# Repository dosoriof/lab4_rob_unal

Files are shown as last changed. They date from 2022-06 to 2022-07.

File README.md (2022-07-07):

# Laboratorio 4 - Robótica Industrial IRB140 
- Rafael Ricardo Galindo
- Diego Fabian Osorio Fonseca
- Christian Cuestas

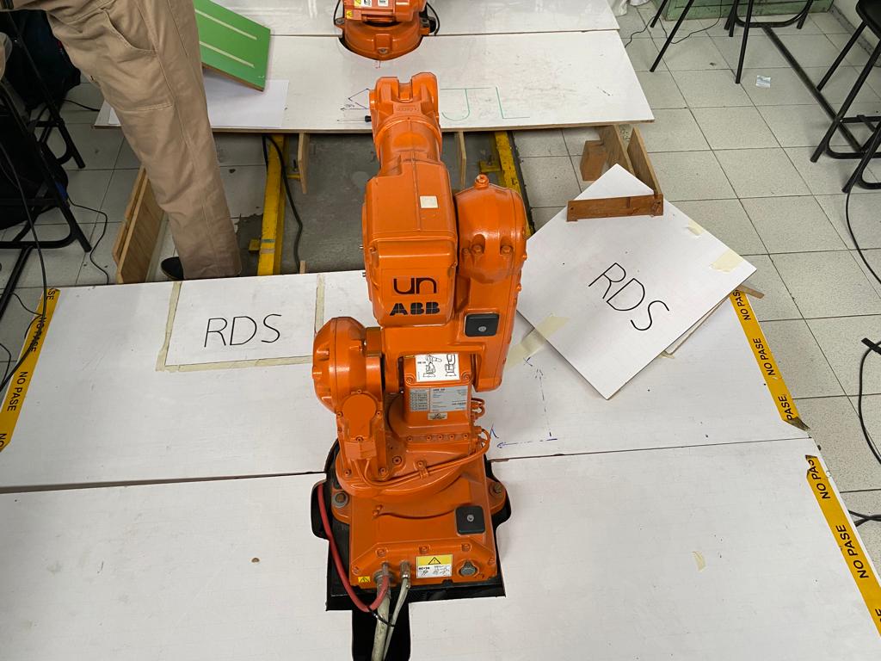
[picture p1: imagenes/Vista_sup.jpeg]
Vista superior


## Herramienta

### Diseño

Para el proceso de fabricación de la herramiento de planteó realizarlo en un modelo CAD y posteriormente realizar la respectiva impresión 3D. El modelo CAD se muestra a continuación:

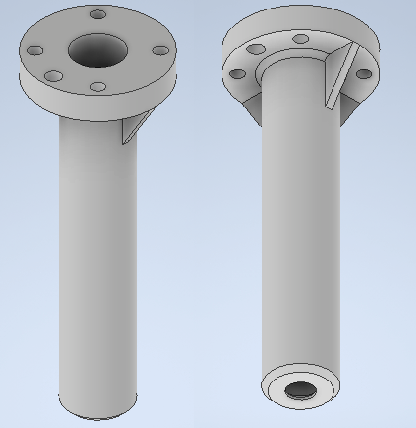
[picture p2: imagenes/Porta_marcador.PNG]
CAD herramienta


Se compone de una base con agujeros M6 (según el manual) para atornillarla a la superficie de anclaje del Robot y además un cilindro hueco para introducir el marcador, con unas cartelas para darle más soporte. El plano con los detalles de las medidas se presenta aquí, y el PDF está en la carpeta:

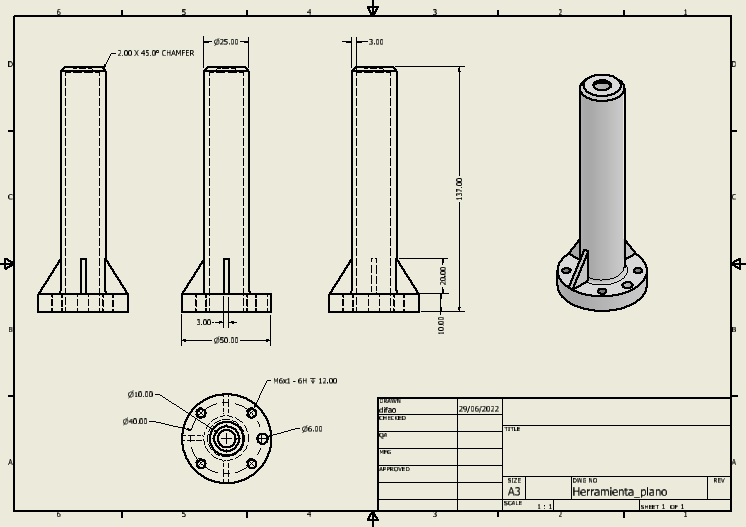
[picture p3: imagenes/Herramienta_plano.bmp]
plano herramienta


Para permitir un juego en el marcador que hace que exista menos resistencia en el momento de realizar los trazos, se dejo un espacio libre en el cilindro y allí se introdujo un resorte, que permite una retracción en el marcador cuando se realiza el contacto con la superficie:

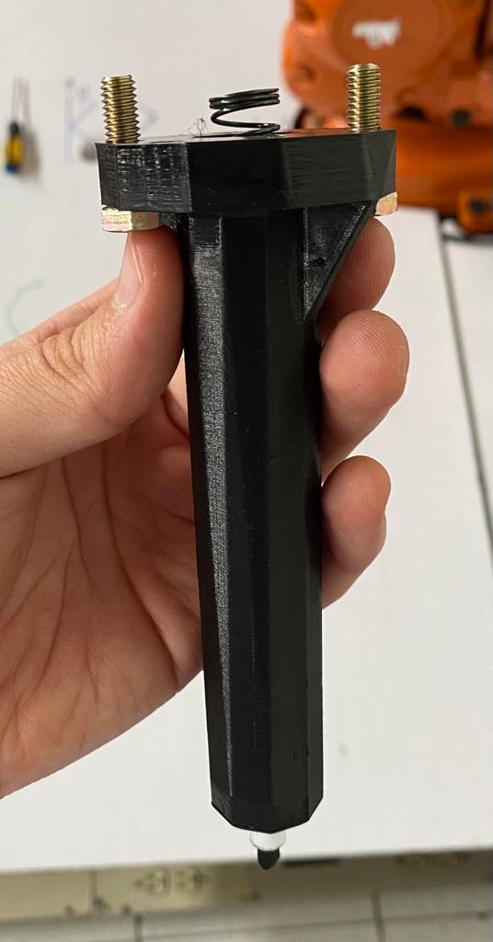
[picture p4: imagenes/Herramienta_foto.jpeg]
herramienta


### Calibración de herramienta en RobotStudio y en IRB140.  
#### Calibración de herramienta en RobotStudio.  
En el modelo de RobotStudio se realiza la importación de la geometría STL de la herramienta, como se muestra en la siguiente imagen:  

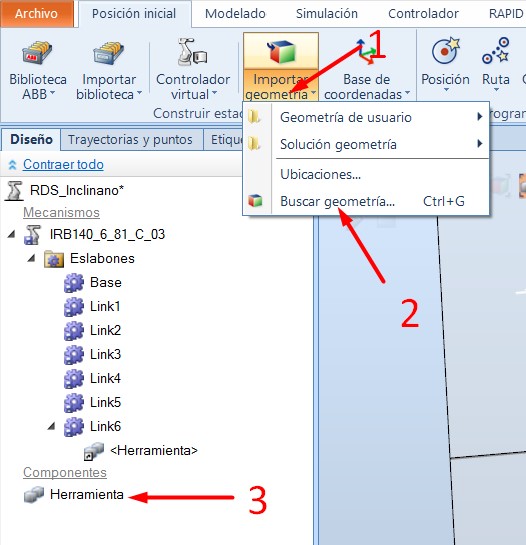
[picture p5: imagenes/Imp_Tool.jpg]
Importar herramienta RobotSutio
   

Teniendo importada la herramienta esta nos aparece posicionada en el origen de la base, en este caso se arrastra en la pestaña de diseño sobre el robot y de esta forma ella se vincula al sistema de coordenadas de la herramienta, sin embargo, la escala no es la correcta, para solucionarlo se siguen los siguientes pasos:

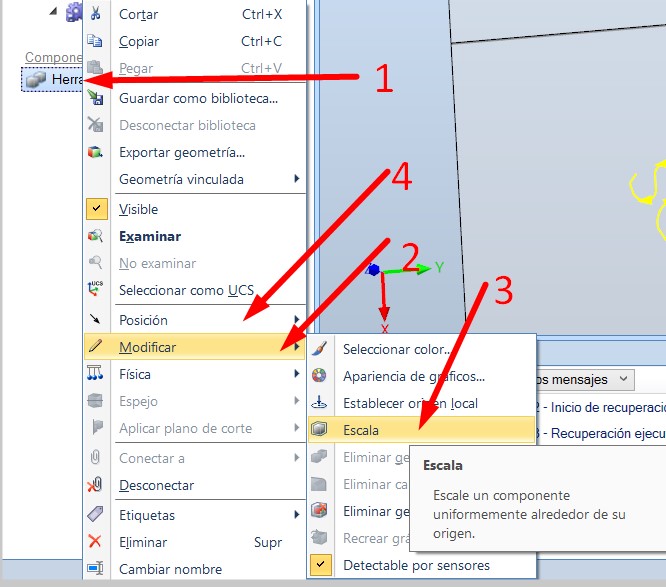
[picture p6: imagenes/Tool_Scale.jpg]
Escalar herramienta
    

Se realiza un proceso similar para ajustar la orientación de la herramienta de forma que quede posicionada correctamente.  
Luego de tener configurada la herramienta se procede a realizar la configuración del sistema de coordenadas de herramienta, para ello se realiza el siguiente proceso:  
Primero se debe crear el dato de la herramienta asi:  

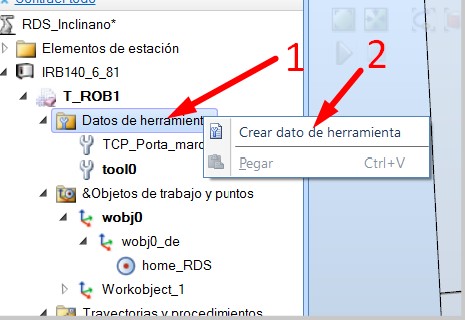
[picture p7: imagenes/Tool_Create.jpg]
Creación del Data Tool.
   

Luego se configura la posición y orientación del sistema de coordenadas de efector final, así:  
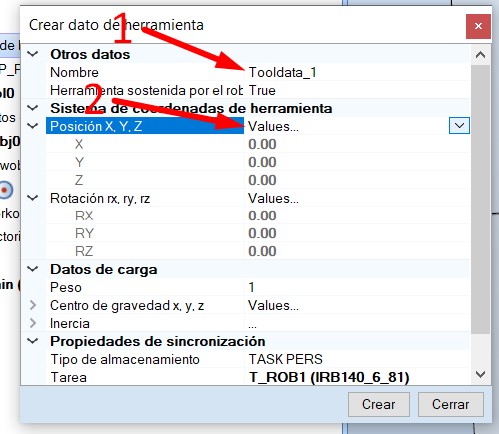
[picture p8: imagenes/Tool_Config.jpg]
Configuración TCP de la herramienta.
   
En este caso de acurdo a la geometría del portaherramientas y la longitud que sobresale del marcador desde la punta se sabe que la herramienta presenta un desfase de 150 mm desde la base de anclaje, se usa este valor para realizar la configuración y se verifica la posición de dicho TCP.  
#### Calibración de herramienta en IRB140 y IRC5.  
Inicialmente se entra a la ventana de Program Data, se selecciona en la pantalla principal tooldata, como se muestra a continuación:  
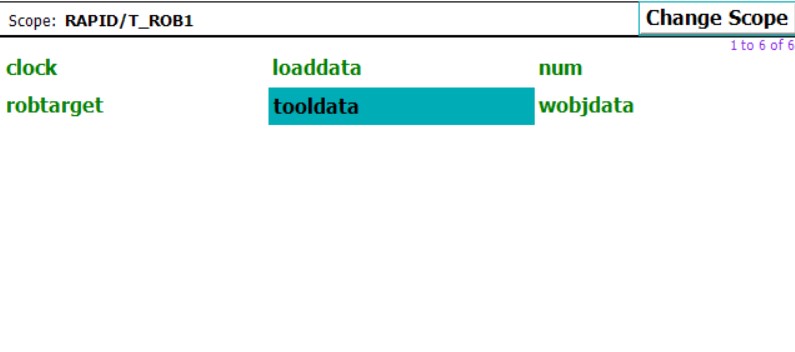
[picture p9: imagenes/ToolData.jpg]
Creación del Data Tool.
   
Luego se da en New, así:  
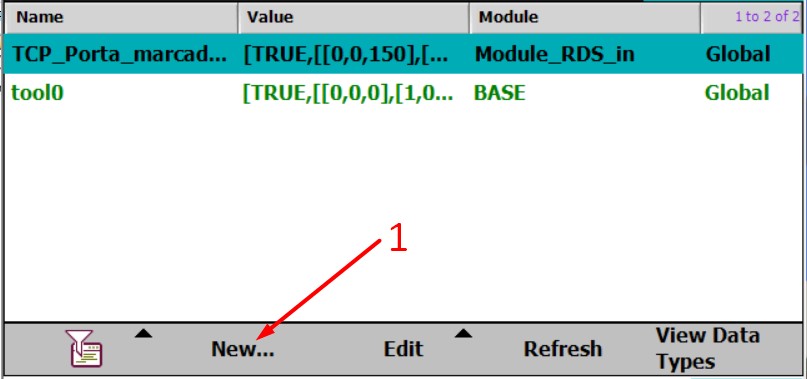
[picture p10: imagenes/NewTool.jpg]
Creación del Data Tool.
   
Luego se le asigna un nombre a la herramienta, y se crea, asi:   
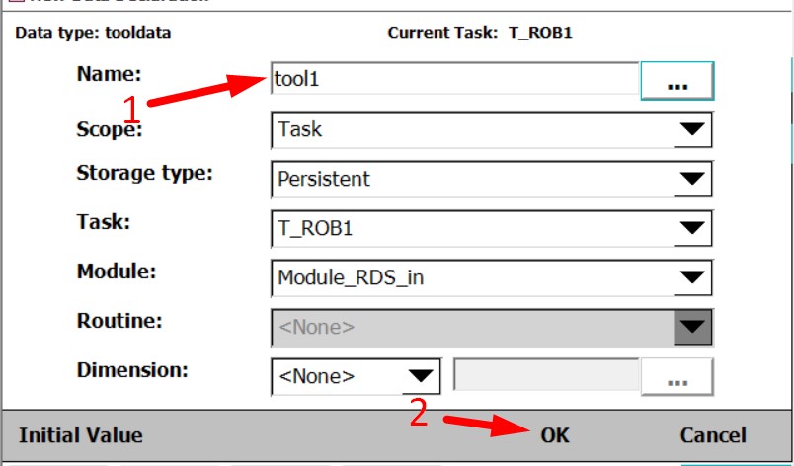
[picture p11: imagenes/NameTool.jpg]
Creación del Data Tool.
   
Luego se selecciona la herramienta recién creada y se inicia el proceso de definición de su configuración, así:  
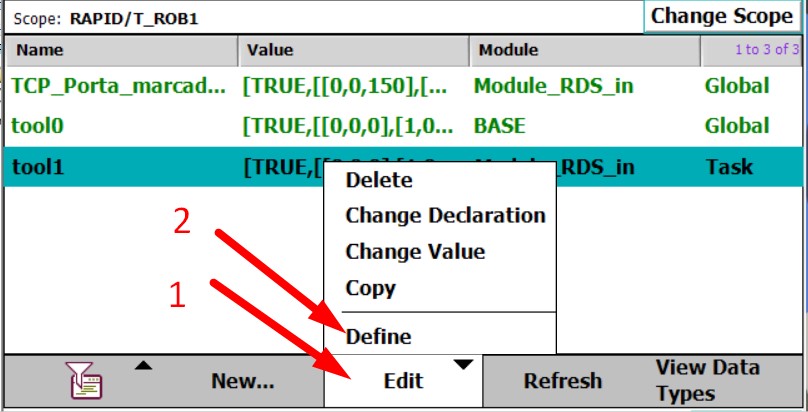
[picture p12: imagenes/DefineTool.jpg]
Creación del Data Tool.
   
En este caso se realiza la definición de la herramienta con 4 puntos en diferentes orientaciones y un punto vertical, para ello se selecciona TPC & Z, así:  
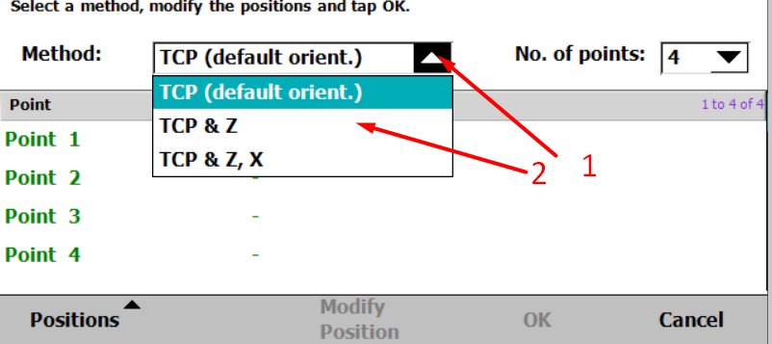
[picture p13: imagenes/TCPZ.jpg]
   
Luego se hace Jogging con el robot hasta las orientaciones y posiciones indicadas en las que la punta de la herramienta alcance la misma posición absoluta, de esta forma el programa puede calcular los desplazamientos relativos que tiene el TCP de la herramienta y adicionalmente calcula con que error esta dado ese punto, de acuerdo a la precisión obtenida en el posicionamiento del robot, esto se hace como se muestra a continuación:   
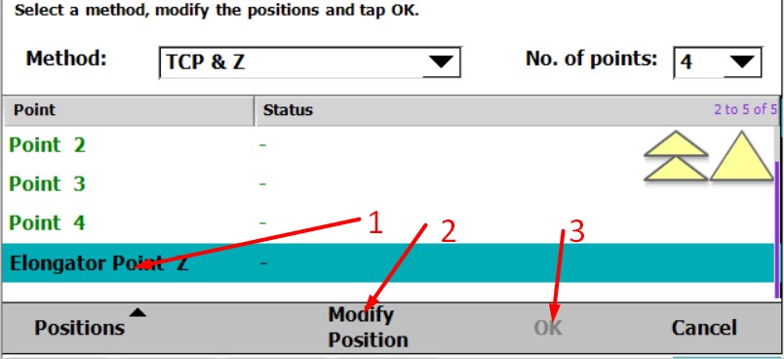
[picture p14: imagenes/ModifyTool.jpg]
Creación del Data Tool.
   

## Trayectorias
### Diseño Trayectoria. 
Para genera la trayectoria se realizó un dibujo en AutoCAD de forma que nos permitirá visualizar la trayectoria deseada y extraer los putos de los vértices y los centros de los arcos, como se muestra a continuación:
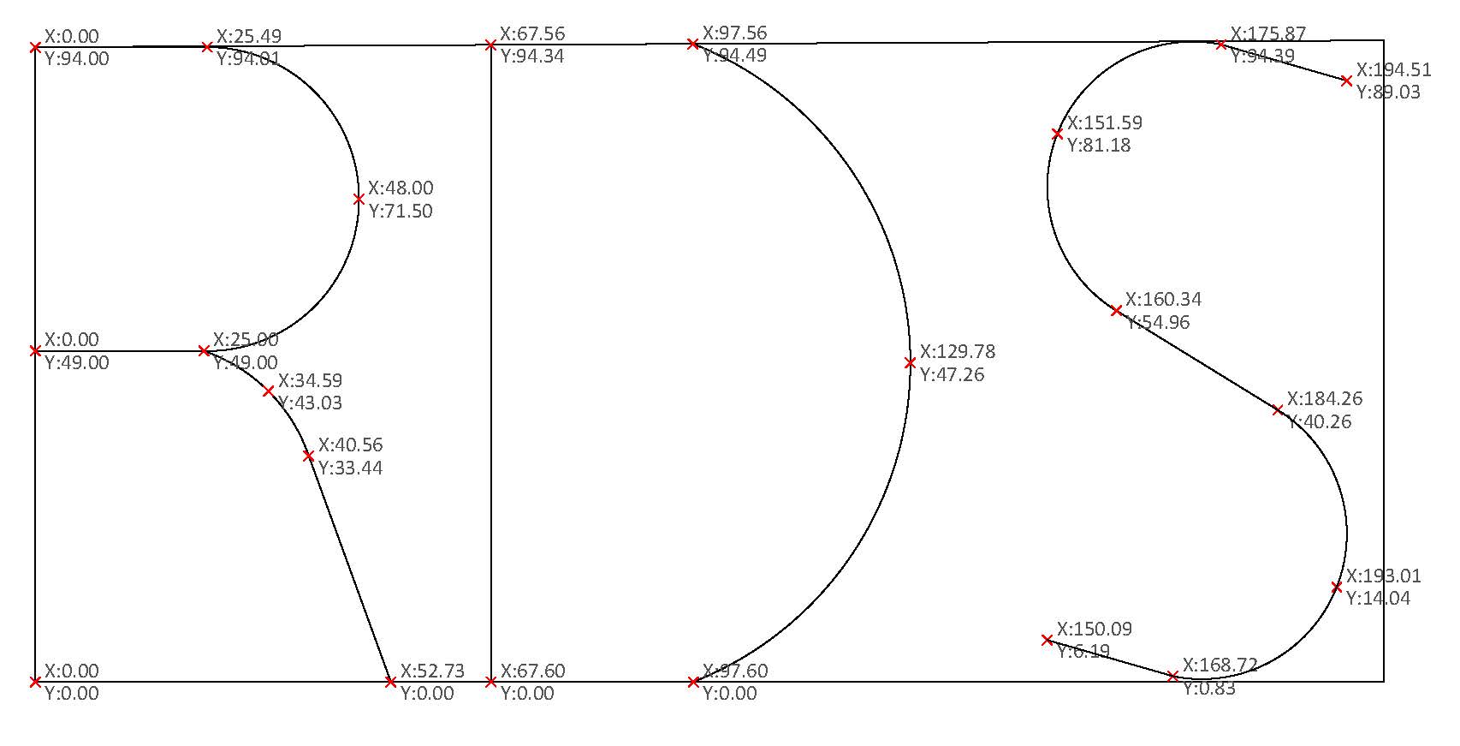
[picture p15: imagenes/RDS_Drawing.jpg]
   
Dicha trayectoria tiene unidades de milímetros y se toman los datos de vértices y centros de arcos, se tomó como origen la esquina de la R y se realizan los trazos en el cuadrante I, x+ , y+; esto se debe tener en cuenta en cómo se realiza el posicionamiento y orientación del sistema de coordenadas del workObject. Adicionalmente en el eje Z todas las coordenadas se manejan en el plano Z=0, excepto en el caso que haya que levantar la herramienta, en este caso se trabaja en plano z=50…
### Definición de los Work Objects.
Como se menciono anteriormente las trayectorias están definidas respecto a su propio sistema de coordenadas, esto se realiza para reutilizar dichas coordendas para los dos casos que se deben realizar, el caso del dibujo en plano y el caso del dibujo en plano inclinado; esto nos obliga realizar la definion de un sistema de coordenamas base para cada trayectoria, esto se conoce como workObject, este se define de acuerdo al sistema de coordenadas de la base.  
Para el primer caso de la trayectoria plana se define el sistema de coordenadas del workObject con solo el origen del plano y las rotaciones indicadas para que la orientación del recorrido sea la deseada, en este caso se rota el eje Z -90°, para obtener las coordenadas del origen se hace Jogging con el robot en coordenadas de base, hasta que la herramienta entre en contacto con la superficie en el punto deseado, en este caso [400, 550, 4].
Para el caso de la trayectoria inclinada se hace uso de una herramienta de definición de sistemas de coordenadas de RobotStudio en la cual se puede definir un sistema de coordenadas con un punto base, un punto sobre el eje x y un punto en el plano xy, como se muestra a continuación:  
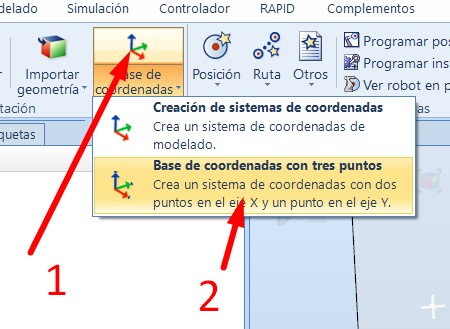
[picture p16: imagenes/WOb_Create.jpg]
   
Para realizar la obtención de dichos puntos se realiza Joggin del robot hasta las posiciones deseadas y se pone en contacto la herramienta con la superficie, se toman dichos valores y el programa realiza el cálculo de desplazamiento y rotaciones necesarias para definir dicho sistema de coordenadas y usarlo como el workObject de referencia para la segunda trayectoria, como se muestra a continuación:  
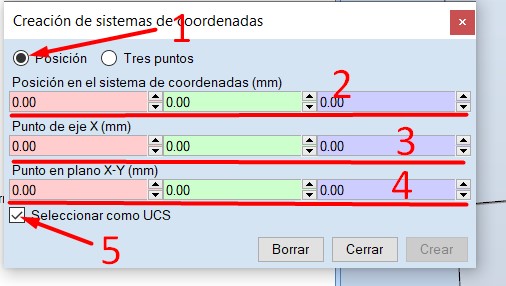
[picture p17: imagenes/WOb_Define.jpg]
   
En el caso de nuestro ejercicio las coordenadas de los puntos de referencia son las siguientes:
P1=[525, -440, 148]; P2=[390, -520, 148]; P3=[503, -595, 207]  
Estas coordenadas nos dan un sistema de referencia con las siguientes características:  
O= [440,-490,148]  
Rx, Ry, Rz=[25.78, 0, -149.35] RPY Euler ZYX Deg.  
Teniendo Creados y definidos los dos sistemas de coordenadas de los workObjects necesarios se procede a programar las trayectorias.

## Resultados

El video con la simulación en Robotstudio y la implementación de la práctica con el robot real se encuentra en el siguiente Link:  **[Video Laboratorio 4](https://youtu.be/TbUIRoGOmfU)**

### Código en RAPID
#### Código para trayectoria en plano.  
```rapid
MODULE Module_RDS
    CONST robtarget home_RDS:=[[636.195461814,0,604.5],[0.5,0,0.866025404,0],[0,0,0,0],[9E+09,9E+09,9E+09,9E+09,9E+09,9E+09]];
    CONST robtarget R_1:=[[0,0,50],[0,0,1,0],[0,0,1,0],[9E+09,9E+09,9E+09,9E+09,9E+09,9E+09]];
    CONST robtarget R_2:=[[0,0,0],[0,0,1,0],[0,0,1,0],[9E+09,9E+09,9E+09,9E+09,9E+09,9E+09]];
    CONST robtarget R_3:=[[0,94,0],[0,0,1,0],[0,0,1,0],[9E+09,9E+09,9E+09,9E+09,9E+09,9E+09]];
    CONST robtarget R_4:=[[25.5,94,0],[0,0,1,0],[0,0,1,0],[9E+09,9E+09,9E+09,9E+09,9E+09,9E+09]];
    CONST robtarget R_5:=[[48,71.5,0],[0,0,1,0],[0,0,1,0],[9E+09,9E+09,9E+09,9E+09,9E+09,9E+09]];
    CONST robtarget R_6:=[[25,49,0],[0,0,1,0],[0,0,1,0],[9E+09,9E+09,9E+09,9E+09,9E+09,9E+09]];
    CONST robtarget R_7:=[[0,49,0],[0,0,1,0],[0,0,1,0],[9E+09,9E+09,9E+09,9E+09,9E+09,9E+09]];
    CONST robtarget R_8:=[[34.5,43,0],[0,0,1,0],[0,0,1,0],[9E+09,9E+09,9E+09,9E+09,9E+09,9E+09]];
    CONST robtarget R_9:=[[40.5,33.5,0],[0,0,1,0],[0,0,0,0],[9E+09,9E+09,9E+09,9E+09,9E+09,9E+09]];
    CONST robtarget R_10:=[[53,0,0],[0,0,1,0],[0,0,0,0],[9E+09,9E+09,9E+09,9E+09,9E+09,9E+09]];
    CONST robtarget R_11:=[[53,0,0],[0,0,1,0],[0,0,0,0],[9E+09,9E+09,9E+09,9E+09,9E+09,9E+09]];
    CONST robtarget D_1:=[[67.6,0,50],[0,0,1,0],[0,0,0,0],[9E+09,9E+09,9E+09,9E+09,9E+09,9E+09]];
    CONST robtarget D_2:=[[67.6,0,0],[0,0,1,0],[0,0,1,0],[9E+09,9E+09,9E+09,9E+09,9E+09,9E+09]];
    CONST robtarget D_3:=[[67.6,94,0],[0,0,1,0],[0,0,1,0],[9E+09,9E+09,9E+09,9E+09,9E+09,9E+09]];
    CONST robtarget D_4:=[[97.5,94,0],[0,0,1,0],[0,0,1,0],[9E+09,9E+09,9E+09,9E+09,9E+09,9E+09]];
    CONST robtarget D_5:=[[130,47,0],[0,0,1,0],[0,0,1,0],[9E+09,9E+09,9E+09,9E+09,9E+09,9E+09]];
    CONST robtarget D_6:=[[97.5,0,0],[0,0,1,0],[0,0,1,0],[9E+09,9E+09,9E+09,9E+09,9E+09,9E+09]];
    CONST robtarget R_12:=[[53,0,50],[0,0,1,0],[0,0,1,0],[9E+09,9E+09,9E+09,9E+09,9E+09,9E+09]];
    CONST robtarget S_1:=[[150,6,50],[0,0,1,0],[0,0,0,0],[9E+09,9E+09,9E+09,9E+09,9E+09,9E+09]];
    CONST robtarget S_2:=[[150,6,0],[0,0,1,0],[0,0,1,0],[9E+09,9E+09,9E+09,9E+09,9E+09,9E+09]];
    CONST robtarget S_3:=[[169,0,0],[0,0,1,0],[0,0,1,0],[9E+09,9E+09,9E+09,9E+09,9E+09,9E+09]];
    CONST robtarget S_4:=[[193,14,0],[0,0,1,0],[0,0,1,0],[9E+09,9E+09,9E+09,9E+09,9E+09,9E+09]];
    CONST robtarget S_5:=[[184,40,0],[0,0,1,0],[0,0,1,0],[9E+09,9E+09,9E+09,9E+09,9E+09,9E+09]];
    CONST robtarget S_6:=[[160,55,0],[0,0,1,0],[0,0,1,0],[9E+09,9E+09,9E+09,9E+09,9E+09,9E+09]];
    CONST robtarget S_7:=[[152,81,0],[0,0,1,0],[0,0,1,0],[9E+09,9E+09,9E+09,9E+09,9E+09,9E+09]];
    CONST robtarget S_8:=[[176,94.5,0],[0,0,1,0],[0,0,1,0],[9E+09,9E+09,9E+09,9E+09,9E+09,9E+09]];
    CONST robtarget S_9:=[[194.5,89,0],[0,0,1,0],[0,0,0,0],[9E+09,9E+09,9E+09,9E+09,9E+09,9E+09]];
    CONST robtarget S_10:=[[194.5,89,50],[0,0,1,0],[0,0,0,0],[9E+09,9E+09,9E+09,9E+09,9E+09,9E+09]];
    PERS tooldata TCP_Porta_marcador:=[TRUE,[[0,0,150],[1,0,0,0]],[1,[0,0,1],[1,0,0,0],0,0,0]];
    TASK PERS wobjdata Workobject_1:=[FALSE,TRUE,"",[[0,0,0],[1,0,0,0]],[[400,550,14],[0.707106781,0,0,-0.707106781]]];
    
!***********************************************************

    PROC main()
        !Añada aquí su código
        MoveJ home_RDS,v200,fine,TCP_Porta_marcador\WObj:=wobj0;
        R;
        D;
        S;
        MoveJ home_RDS,v200,fine,TCP_Porta_marcador\WObj:=wobj0;
    ENDPROC
    PROC R()
        MoveJ R_1,v200,fine,TCP_Porta_marcador\WObj:=Workobject_1;
        MoveL R_2,v100,fine,TCP_Porta_marcador\WObj:=Workobject_1;
        MoveL R_3,v100,fine,TCP_Porta_marcador\WObj:=Workobject_1;
        MoveL R_4,v100,fine,TCP_Porta_marcador\WObj:=Workobject_1;
        MoveC R_5,R_6,v100,fine,TCP_Porta_marcador\WObj:=Workobject_1;
        MoveL R_7,v100,fine,TCP_Porta_marcador\WObj:=Workobject_1;
        MoveL R_6,v100,fine,TCP_Porta_marcador\WObj:=Workobject_1;
        MoveC R_8,R_9,v100,fine,TCP_Porta_marcador\WObj:=Workobject_1;
        MoveL R_10,v100,fine,TCP_Porta_marcador\WObj:=Workobject_1;
        MoveL R_11,v100,fine,TCP_Porta_marcador\WObj:=Workobject_1;
        MoveL R_12,v100,fine,TCP_Porta_marcador\WObj:=Workobject_1;
    ENDPROC
    PROC D()
        MoveL D_1,v100,fine,TCP_Porta_marcador\WObj:=Workobject_1;
        MoveL D_2,v100,fine,TCP_Porta_marcador\WObj:=Workobject_1;
        MoveL D_3,v100,fine,TCP_Porta_marcador\WObj:=Workobject_1;
        MoveL D_4,v100,fine,TCP_Porta_marcador\WObj:=Workobject_1;
        MoveC D_5,D_6,v100,fine,TCP_Porta_marcador\WObj:=Workobject_1;
        MoveL D_2,v100,fine,TCP_Porta_marcador\WObj:=Workobject_1;
        MoveL D_1,v100,fine,TCP_Porta_marcador\WObj:=Workobject_1;
    ENDPROC
    PROC S()
        MoveL S_1,v100,fine,TCP_Porta_marcador\WObj:=Workobject_1;
        MoveL S_2,v100,fine,TCP_Porta_marcador\WObj:=Workobject_1;
        MoveL S_3,v100,fine,TCP_Porta_marcador\WObj:=Workobject_1;
        MoveC S_4,S_5,v100,fine,TCP_Porta_marcador\WObj:=Workobject_1;
        MoveL S_6,v100,fine,TCP_Porta_marcador\WObj:=Workobject_1;
        MoveC S_7,S_8,v100,fine,TCP_Porta_marcador\WObj:=Workobject_1;
        MoveL S_9,v100,fine,TCP_Porta_marcador\WObj:=Workobject_1;
        MoveL S_10,v100,fine,TCP_Porta_marcador\WObj:=Workobject_1;
    ENDPROC
ENDMODULE
```

#### Código para trayectoria en plano inclinado.  
```rapid
MODULE Module_RDS_in
    CONST robtarget home_RDS:=[[636.195461814,0,604.5],[0.5,0,0.866025404,0],[0,0,0,0],[9E+09,9E+09,9E+09,9E+09,9E+09,9E+09]];
    CONST robtarget R_1:=[[0,0,50],[0,0,1,0],[0,0,1,0],[9E+09,9E+09,9E+09,9E+09,9E+09,9E+09]];
    CONST robtarget R_2:=[[0,0,0],[0,0,1,0],[0,0,1,0],[9E+09,9E+09,9E+09,9E+09,9E+09,9E+09]];
    CONST robtarget R_3:=[[0,94,0],[0,0,1,0],[0,0,1,0],[9E+09,9E+09,9E+09,9E+09,9E+09,9E+09]];
    CONST robtarget R_4:=[[25.5,94,0],[0,0,1,0],[0,0,1,0],[9E+09,9E+09,9E+09,9E+09,9E+09,9E+09]];
    CONST robtarget R_5:=[[48,71.5,0],[0,0,1,0],[0,0,1,0],[9E+09,9E+09,9E+09,9E+09,9E+09,9E+09]];
    CONST robtarget R_6:=[[25,49,0],[0,0,1,0],[0,0,1,0],[9E+09,9E+09,9E+09,9E+09,9E+09,9E+09]];
    CONST robtarget R_7:=[[0,49,0],[0,0,1,0],[0,0,1,0],[9E+09,9E+09,9E+09,9E+09,9E+09,9E+09]];
    CONST robtarget R_8:=[[34.5,43,0],[0,0,1,0],[0,0,1,0],[9E+09,9E+09,9E+09,9E+09,9E+09,9E+09]];
    CONST robtarget R_9:=[[40.5,33.5,0],[0,0,1,0],[0,0,0,0],[9E+09,9E+09,9E+09,9E+09,9E+09,9E+09]];
    CONST robtarget R_10:=[[53,0,0],[0,0,1,0],[0,0,0,0],[9E+09,9E+09,9E+09,9E+09,9E+09,9E+09]];
    CONST robtarget R_11:=[[53,0,0],[0,0,1,0],[0,0,0,0],[9E+09,9E+09,9E+09,9E+09,9E+09,9E+09]];
    CONST robtarget D_1:=[[67.6,0,50],[0,0,1,0],[0,0,0,0],[9E+09,9E+09,9E+09,9E+09,9E+09,9E+09]];
    CONST robtarget D_2:=[[67.6,0,0],[0,0,1,0],[0,0,1,0],[9E+09,9E+09,9E+09,9E+09,9E+09,9E+09]];
    CONST robtarget D_3:=[[67.6,94,0],[0,0,1,0],[0,0,1,0],[9E+09,9E+09,9E+09,9E+09,9E+09,9E+09]];
    CONST robtarget D_4:=[[97.5,94,0],[0,0,1,0],[0,0,1,0],[9E+09,9E+09,9E+09,9E+09,9E+09,9E+09]];
    CONST robtarget D_5:=[[130,47,0],[0,0,1,0],[0,0,1,0],[9E+09,9E+09,9E+09,9E+09,9E+09,9E+09]];
    CONST robtarget D_6:=[[97.5,0,0],[0,0,1,0],[0,0,1,0],[9E+09,9E+09,9E+09,9E+09,9E+09,9E+09]];
    CONST robtarget R_12:=[[53,0,50],[0,0,1,0],[0,0,1,0],[9E+09,9E+09,9E+09,9E+09,9E+09,9E+09]];
    CONST robtarget S_1:=[[150,6,50],[0,0,1,0],[0,0,0,0],[9E+09,9E+09,9E+09,9E+09,9E+09,9E+09]];
    CONST robtarget S_2:=[[150,6,0],[0,0,1,0],[0,0,1,0],[9E+09,9E+09,9E+09,9E+09,9E+09,9E+09]];
    CONST robtarget S_3:=[[169,0,0],[0,0,1,0],[0,0,1,0],[9E+09,9E+09,9E+09,9E+09,9E+09,9E+09]];
    CONST robtarget S_4:=[[193,14,0],[0,0,1,0],[0,0,1,0],[9E+09,9E+09,9E+09,9E+09,9E+09,9E+09]];
    CONST robtarget S_5:=[[184,40,0],[0,0,1,0],[0,0,1,0],[9E+09,9E+09,9E+09,9E+09,9E+09,9E+09]];
    CONST robtarget S_6:=[[160,55,0],[0,0,1,0],[0,0,1,0],[9E+09,9E+09,9E+09,9E+09,9E+09,9E+09]];
    CONST robtarget S_7:=[[152,81,0],[0,0,1,0],[0,0,1,0],[9E+09,9E+09,9E+09,9E+09,9E+09,9E+09]];
    CONST robtarget S_8:=[[176,94.5,0],[0,0,1,0],[0,0,1,0],[9E+09,9E+09,9E+09,9E+09,9E+09,9E+09]];
    CONST robtarget S_9:=[[194.5,89,0],[0,0,1,0],[0,0,0,0],[9E+09,9E+09,9E+09,9E+09,9E+09,9E+09]];
    CONST robtarget S_10:=[[194.5,89,50],[0,0,1,0],[0,0,0,0],[9E+09,9E+09,9E+09,9E+09,9E+09,9E+09]];
    PERS tooldata TCP_Porta_marcador:=[TRUE,[[0,0,150],[1,0,0,0]],[1,[0,0,1],[1,0,0,0],0,0,0]];
    TASK PERS wobjdata Workobject_1:=[FALSE,TRUE,"",[[440,-490,148],[0.257633724,0.058958677,-0.215147749,-0.940138386]],[[0,0,0],[1,0,0,0]]];
    TASK PERS tooldata tool1:=[TRUE,[[0,0,0],[1,0,0,0]],[-1,[0,0,0],[1,0,0,0],0,0,0]];
    
!***********************************************************

    PROC main()
        !Añada aquí su código
        MoveJ home_RDS,v200,fine,TCP_Porta_marcador\WObj:=wobj0;
        R;
        D;
        S;
        MoveJ home_RDS,v200,fine,TCP_Porta_marcador\WObj:=wobj0;
    ENDPROC
    PROC R()
        MoveJ R_1,v200,fine,TCP_Porta_marcador\WObj:=Workobject_1;
        MoveL R_2,v100,fine,TCP_Porta_marcador\WObj:=Workobject_1;
        MoveL R_3,v100,fine,TCP_Porta_marcador\WObj:=Workobject_1;
        MoveL R_4,v100,fine,TCP_Porta_marcador\WObj:=Workobject_1;
        MoveC R_5,R_6,v100,fine,TCP_Porta_marcador\WObj:=Workobject_1;
        MoveL R_7,v100,fine,TCP_Porta_marcador\WObj:=Workobject_1;
        MoveL R_6,v100,fine,TCP_Porta_marcador\WObj:=Workobject_1;
        MoveC R_8,R_9,v100,fine,TCP_Porta_marcador\WObj:=Workobject_1;
        MoveL R_10,v100,fine,TCP_Porta_marcador\WObj:=Workobject_1;
        MoveL R_11,v100,fine,TCP_Porta_marcador\WObj:=Workobject_1;
        MoveL R_12,v100,fine,TCP_Porta_marcador\WObj:=Workobject_1;
    ENDPROC
    PROC D()
        MoveL D_1,v100,fine,TCP_Porta_marcador\WObj:=Workobject_1;
        MoveL D_2,v100,fine,TCP_Porta_marcador\WObj:=Workobject_1;
        MoveL D_3,v100,fine,TCP_Porta_marcador\WObj:=Workobject_1;
        MoveL D_4,v100,fine,TCP_Porta_marcador\WObj:=Workobject_1;
        MoveC D_5,D_6,v100,fine,TCP_Porta_marcador\WObj:=Workobject_1;
        MoveL D_2,v100,fine,TCP_Porta_marcador\WObj:=Workobject_1;
        MoveL D_1,v100,fine,TCP_Porta_marcador\WObj:=Workobject_1;
    ENDPROC
    PROC S()
        MoveL S_1,v100,fine,TCP_Porta_marcador\WObj:=Workobject_1;
        MoveL S_2,v100,fine,TCP_Porta_marcador\WObj:=Workobject_1;
        MoveL S_3,v100,fine,TCP_Porta_marcador\WObj:=Workobject_1;
        MoveC S_4,S_5,v100,fine,TCP_Porta_marcador\WObj:=Workobject_1;
        MoveL S_6,v100,fine,TCP_Porta_marcador\WObj:=Workobject_1;
        MoveC S_7,S_8,v100,fine,TCP_Porta_marcador\WObj:=Workobject_1;
        MoveL S_9,v100,fine,TCP_Porta_marcador\WObj:=Workobject_1;
        MoveL S_10,v100,fine,TCP_Porta_marcador\WObj:=Workobject_1;
    ENDPROC
ENDMODULE

```
## Conclusiones
* Al momento de planear trayectoria es importante definir workObjects de forma que se pueda tener un sistema de coordenadas independiente y así se puedan alterar la trayectoria sin tener que modificar los puntos. De esta forma se pueden realizar ajustes en campo sin implicar demasiadas modificaciones al código.
* Al momento de modificar un workObject en el cual ya existen trayectorias definidas existen unos límites de desplazamiento y orientación entre los cuales el programa funciona sin inconveniente, sin embargo, cuando para llegar a alguna posición el robot requiere una nueva configuración el sistema presenta errores, ya que estas nuevas configuraciones deben definirse directamente en el Target, por lo cual cuando las trayectorias requieran nuevas configuraciones, se deben tener en cuenta al momento de la creación del Target.   
* Al momento de realizar una calibración de la herramienta es importante poder visualizar con precisión el punto central de la herramienta para poder obtener buena calida con error bajo en dicha calibración.    
* En los casos en que el robot tenga que interactuar con el espacio y este no esté muy bien mapeado o sea móvil, es importante prever ciertos desajustes y faltas de precisión por lo tanto es fundamental que las herramientas tengas un diseño con holgura o juego, en este caso se colocó un resorte que mantenía el marcador en contacto, pero le permite retraerse aproximadamente 1.5 cm. De esta forma no existe gran riesgo de accidentes o daños en los equipos y los entornos de trabajo.

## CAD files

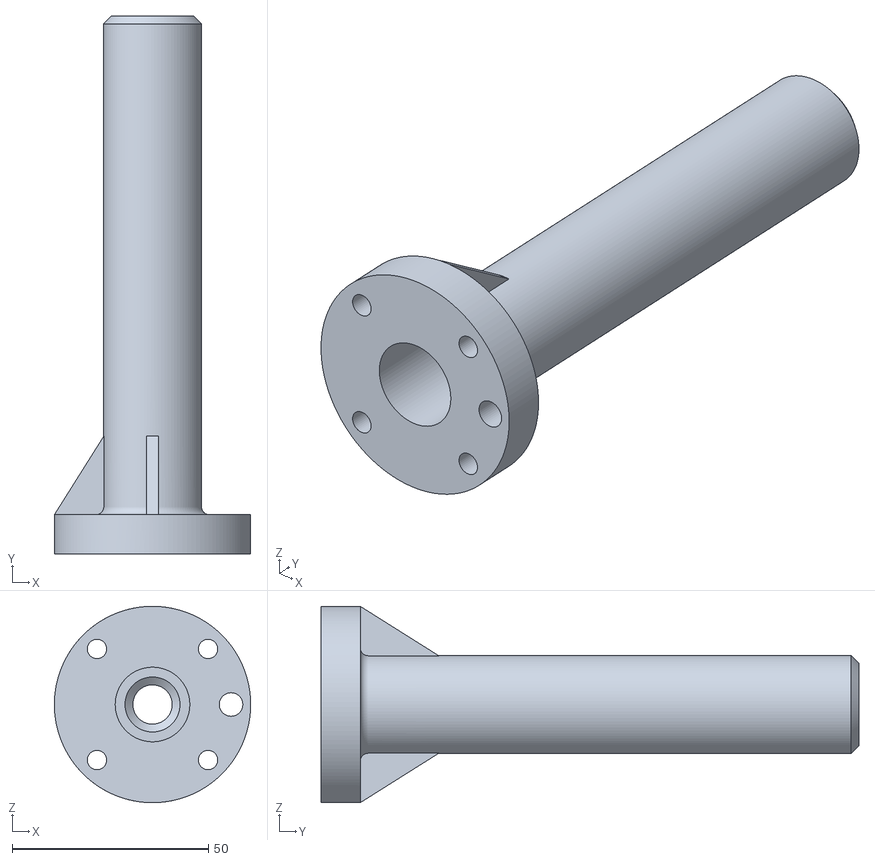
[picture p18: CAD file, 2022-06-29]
Herramienta/Herramienta.stl
50.0 x 137.0 x 50.0

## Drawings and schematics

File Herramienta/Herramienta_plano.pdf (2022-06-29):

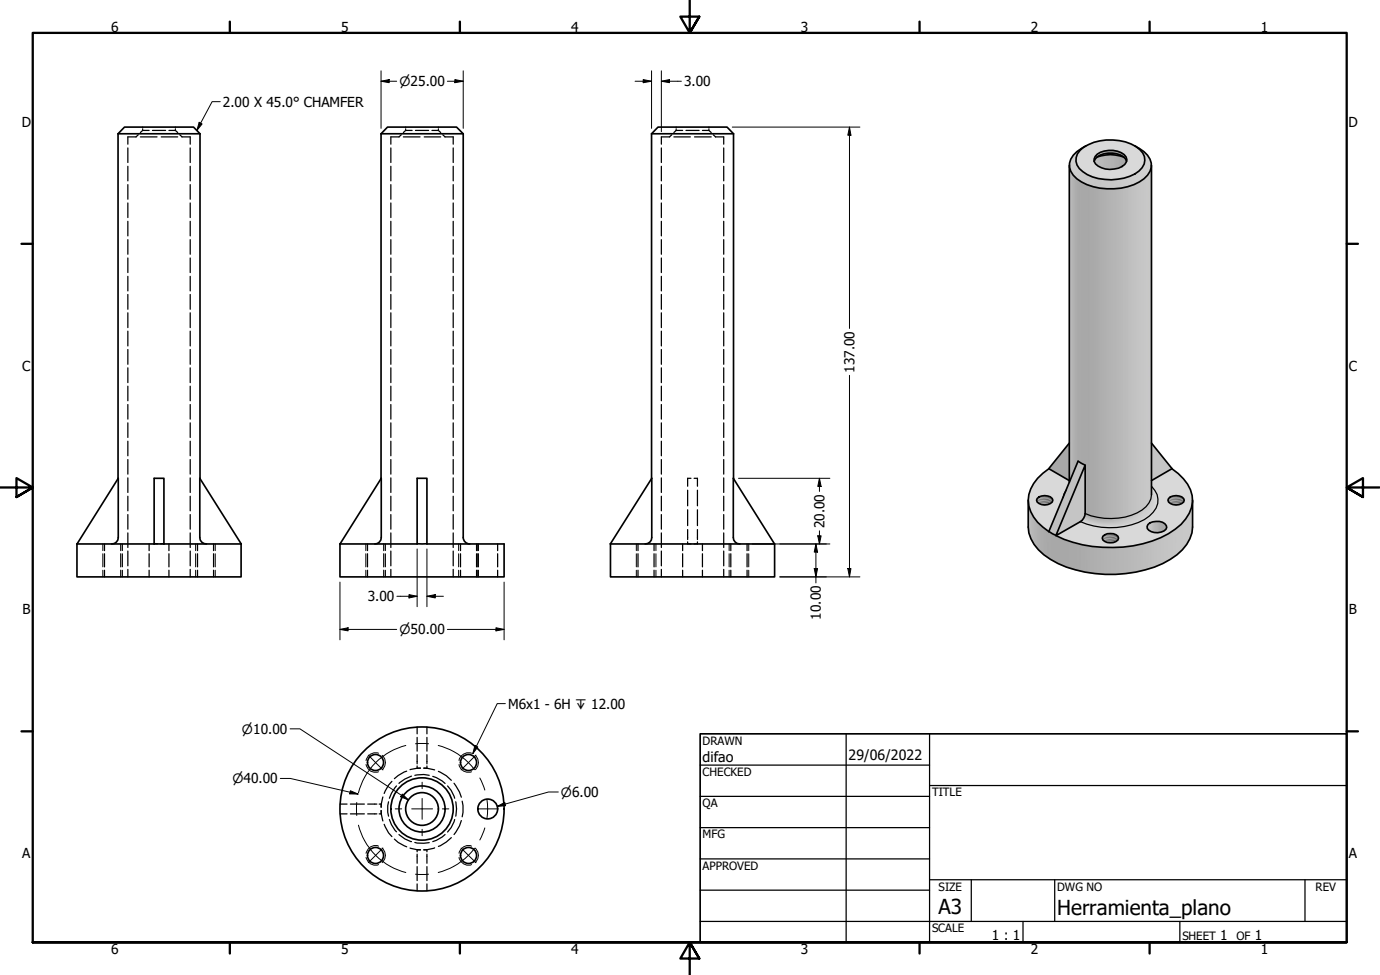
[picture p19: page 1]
2.00 X 45.0° CHAMFER

DRAWN difao | 29/06/2022

CHECKED

MFG

APPROVED

SIZE A3 | DWG NO Herramienta_plano | REV

SCALE 1 : 1 | | SHEET 1 OF 1
